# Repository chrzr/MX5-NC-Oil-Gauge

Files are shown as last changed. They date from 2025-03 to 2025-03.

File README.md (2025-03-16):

# MX5-NC-Oil-Gauge

So my inspiration was obviously the fantastic gauge kit from Rotarytronics! But as i did not want to modify my gauge cluster, I decided to try and come up with something myself :)
(the provided installation manual also gives some information about the installation process of the sensor)

I used the following hardware:

- Waveshare RP2040 1.28" LCD Touchscreen
  https://www.waveshare.com/rp2040-touch-lcd-1.28.htm
- Custom 3D printed gauge pod
  based on https://www.printables.com/model/538771-rp2040-lcd-128-msa
- Bosch 0261230340 combined oil pressure and temperature sensor
  https://www.speedingparts.de/p/motorsteuerung/motorsteuerung-4623/sensor/drucksensor/bosch-flssigkeitsdruck-und-temperatursensor-10bar-140-c.html you should be able to find the datasheet by searching for the partnumber
- Bosch F 02U B00 751-01 5 pin trapez connector for connecting the sensor
  https://www.bosch-motorsport-shop.com.au/mating-connector-5-pin-trapez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
- 1/4" NPT to M10x1.0 thread adaptor (oil filter housing is 1/4" NPT inner thread, sensor has M10x1.0 outer thread)
  https://www.speedingparts.de/p/kraftstoff-dash-leitungssysteme/an-anschlsse-an-leitungen/spd-an-fittings/mm-npt-npt-reduzierstck/14-npt-m10x10-verringerung.html (you should be able to find similar ones on aliexpress)
- ADS1115 ADC for data aquisition from the sensors
  https://www.az-delivery.de/en/products/analog-digitalwandler-ads1115-mit-i2c-interface
- 5V to 3.3 logic level converter to get the ADCs 5V I2C signal down to the 3.3V input level of the RP2040
  https://www.sparkfun.com/sparkfun-logic-level-converter-bi-directional.html
- 12V IN to 5V / 3.3V OUT Breadboard PSU
  https://www.az-delivery.de/en/products/mb102-breadboard
- Fuse tap (Mini fuse size) to get the 12V from the driverside footwell fusebox
  https://www.aliexpress.com/item/4000648828410.html
- Prototyping pcb for the ADC, LLC, and PSU
  https://www.aliexpress.com/item/1005008313272396.html
- A few meters of 4-strand 4x0,5 mm² sensor wire

The setup is as follows: The RP2040 with the LCD sits inside the gauge pod and is connected via an about 75cm long piece of an old USB cable to the ADC/PSU box, which I placed in the driver footwell area above the fusebox. The PSU gets 12V from the driver footwell fusebox and supplies 5V to the ADC and 3.3V to the RP2040. The sensor is directly connected to the ADC box (i routed the wire through the rubber grommet of the hood release cable)
The circuitry for interfacing the sensor was a bit fiddly ... be sure to connect the thermistor via a pull-down resistor (I used 1k Ohm)

Getting the old sensor out and installing the new one was a bit tricky because of the limited space + I have large hands and only had the car on jack stands. I would definitely recommend a long 27mm socket and some extensions.

Using snippets (mainly the driver part) from this repository: https://github.com/waveshareteam/RP2040-Touch-LCD-1.28

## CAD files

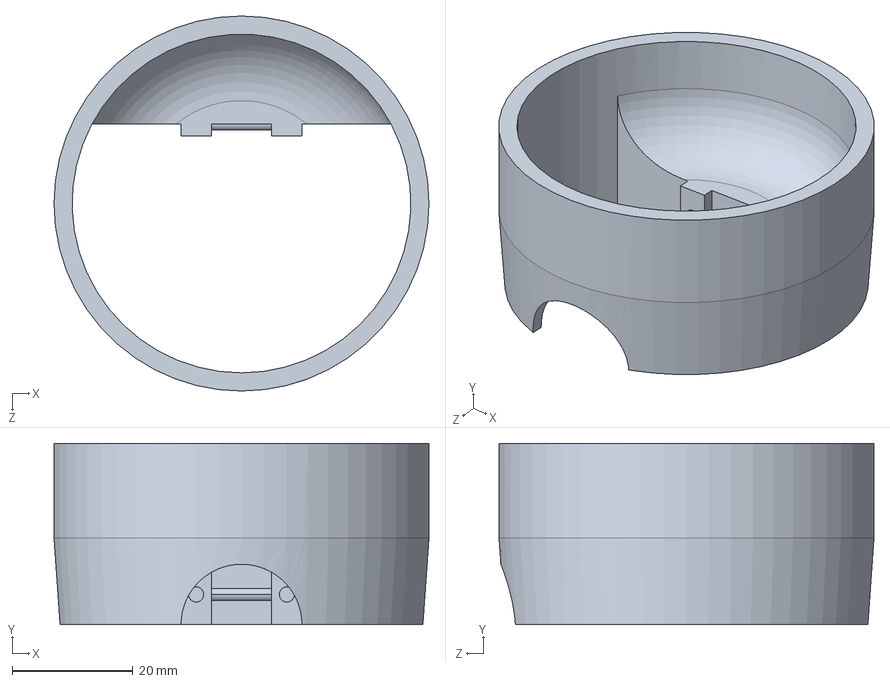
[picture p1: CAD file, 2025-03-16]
MX5_OilGaugePod.SLDPRT
62.0 x 30.0 x 62.0 mm

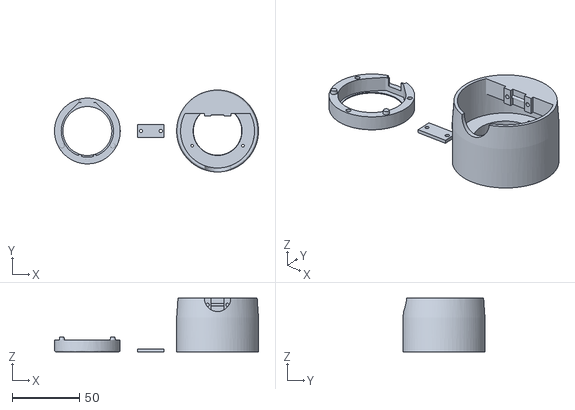
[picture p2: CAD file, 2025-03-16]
MX5_NC_GaugePod.stl
152.0 x 61.0 x 40.0

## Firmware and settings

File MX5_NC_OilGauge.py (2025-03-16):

from machine import Pin,I2C,SPI,PWM,Timer
import framebuf
import time
import math
Vbat_Pin = 29

#Pin definition  引脚定义
I2C_SDA = 6
I2C_SDL = 7

DC = 8
CS = 9
SCK = 10
MOSI = 11
MISO = 12
RST = 13

BL = 25

###########################################################################################################
####################################### DRIVERS START #####################################################
###########################################################################################################

#LCD Driver  LCD驱动
class LCD_1inch28(framebuf.FrameBuffer):
    def __init__(self): #SPI initialization  SPI初始化
        self.width = 240
        self.height = 240
        
        self.cs = Pin(CS,Pin.OUT)
        self.rst = Pin(RST,Pin.OUT)
        
        self.cs(1)
        self.spi = SPI(1,100_000_000,polarity=0, phase=0,bits= 8,sck=Pin(SCK),mosi=Pin(MOSI),miso=None)
        self.dc = Pin(DC,Pin.OUT)
        self.dc(1)
        self.buffer = bytearray(self.height * self.width * 2)
        super().__init__(self.buffer, self.width, self.height, framebuf.RGB565)
        self.init_display()
        
        #Define color, Micropython fixed to BRG format  定义颜色，Micropython固定为BRG格式
        self.red   =   0x07E0
        self.green =   0x001f
        self.blue  =   0xf800
        self.white =   0xffff
        self.black =   0x0000
        self.brown =   0X8430
        
        self.fill(self.white) #Clear screen  清屏
        self.show()#Show  显示

        self.pwm = PWM(Pin(BL))
        self.pwm.freq(5000) #Turn on the backlight  开背光
        
    def write_cmd(self, cmd): #Write command  写命令
        self.cs(1)
        self.dc(0)
        self.cs(0)
        self.spi.write(bytearray([cmd]))
        self.cs(1)

    def write_data(self, buf): #Write data  写数据
        self.cs(1)
        self.dc(1)
        self.cs(0)
        self.spi.write(bytearray([buf]))
        self.cs(1)
        
    def set_bl_pwm(self,duty): #Set screen brightness  设置屏幕亮度
        self.pwm.duty_u16(duty)#max 65535
        
    def init_display(self): #LCD initialization  LCD初始化
        """Initialize dispaly"""  
        self.rst(1)
        time.sleep(0.01)
        self.rst(0)
        time.sleep(0.01)
        self.rst(1)
        time.sleep(0.05)
        
        self.write_cmd(0xEF)
        self.write_cmd(0xEB)
        self.write_data(0x14) 
        
        self.write_cmd(0xFE) 
        self.write_cmd(0xEF) 

        self.write_cmd(0xEB)
        self.write_data(0x14) 

        self.write_cmd(0x84)
        self.write_data(0x40) 

        self.write_cmd(0x85)
        self.write_data(0xFF) 

        self.write_cmd(0x86)
        self.write_data(0xFF) 

        self.write_cmd(0x87)
        self.write_data(0xFF)

        self.write_cmd(0x88)
        self.write_data(0x0A)

        self.write_cmd(0x89)
        self.write_data(0x21) 

        self.write_cmd(0x8A)
        self.write_data(0x00) 

        self.write_cmd(0x8B)
        self.write_data(0x80) 

        self.write_cmd(0x8C)
        self.write_data(0x01) 

        self.write_cmd(0x8D)
        self.write_data(0x01) 

        self.write_cmd(0x8E)
        self.write_data(0xFF) 

        self.write_cmd(0x8F)
        self.write_data(0xFF) 


        self.write_cmd(0xB6)
        self.write_data(0x00)
        self.write_data(0x20)

        self.write_cmd(0x36)
        self.write_data(0x98)

        self.write_cmd(0x3A)
        self.write_data(0x05) 


        self.write_cmd(0x90)
        self.write_data(0x08)
        self.write_data(0x08)
        self.write_data(0x08)
        self.write_data(0x08) 

        self.write_cmd(0xBD)
        self.write_data(0x06)
        
        self.write_cmd(0xBC)
        self.write_data(0x00)

        self.write_cmd(0xFF)
        self.write_data(0x60)
        self.write_data(0x01)
        self.write_data(0x04)

        self.write_cmd(0xC3)
        self.write_data(0x13)
        self.write_cmd(0xC4)
        self.write_data(0x13)

        self.write_cmd(0xC9)
        self.write_data(0x22)

        self.write_cmd(0xBE)
        self.write_data(0x11) 

        self.write_cmd(0xE1)
        self.write_data(0x10)
        self.write_data(0x0E)

        self.write_cmd(0xDF)
        self.write_data(0x21)
        self.write_data(0x0c)
        self.write_data(0x02)

        self.write_cmd(0xF0)   
        self.write_data(0x45)
        self.write_data(0x09)
        self.write_data(0x08)
        self.write_data(0x08)
        self.write_data(0x26)
        self.write_data(0x2A)

        self.write_cmd(0xF1)    
        self.write_data(0x43)
        self.write_data(0x70)
        self.write_data(0x72)
        self.write_data(0x36)
        self.write_data(0x37)  
        self.write_data(0x6F)


        self.write_cmd(0xF2)   
        self.write_data(0x45)
        self.write_data(0x09)
        self.write_data(0x08)
        self.write_data(0x08)
        self.write_data(0x26)
        self.write_data(0x2A)

        self.write_cmd(0xF3)   
        self.write_data(0x43)
        self.write_data(0x70)
        self.write_data(0x72)
        self.write_data(0x36)
        self.write_data(0x37) 
        self.write_data(0x6F)

        self.write_cmd(0xED)
        self.write_data(0x1B) 
        self.write_data(0x0B) 

        self.write_cmd(0xAE)
        self.write_data(0x77)
        
        self.write_cmd(0xCD)
        self.write_data(0x63)


        self.write_cmd(0x70)
        self.write_data(0x07)
        self.write_data(0x07)
        self.write_data(0x04)
        self.write_data(0x0E) 
        self.write_data(0x0F) 
        self.write_data(0x09)
        self.write_data(0x07)
        self.write_data(0x08)
        self.write_data(0x03)

        self.write_cmd(0xE8)
        self.write_data(0x34)

        self.write_cmd(0x62)
        self.write_data(0x18)
        self.write_data(0x0D)
        self.write_data(0x71)
        self.write_data(0xED)
        self.write_data(0x70) 
        self.write_data(0x70)
        self.write_data(0x18)
        self.write_data(0x0F)
        self.write_data(0x71)
        self.write_data(0xEF)
        self.write_data(0x70) 
        self.write_data(0x70)

        self.write_cmd(0x63)
        self.write_data(0x18)
        self.write_data(0x11)
        self.write_data(0x71)
        self.write_data(0xF1)
        self.write_data(0x70) 
        self.write_data(0x70)
        self.write_data(0x18)
        self.write_data(0x13)
        self.write_data(0x71)
        self.write_data(0xF3)
        self.write_data(0x70) 
        self.write_data(0x70)

        self.write_cmd(0x64)
        self.write_data(0x28)
        self.write_data(0x29)
        self.write_data(0xF1)
        self.write_data(0x01)
        self.write_data(0xF1)
        self.write_data(0x00)
        self.write_data(0x07)
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

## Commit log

2025-03-16 initial commit
    Added python script and STL file for NC air vent gauge pod
    [MX5_NC_GaugePod.stl]
2025-03-16 added Solidworks base file for NC vent adaptor
    [MX5_OilGaugePod.SLDPRT]

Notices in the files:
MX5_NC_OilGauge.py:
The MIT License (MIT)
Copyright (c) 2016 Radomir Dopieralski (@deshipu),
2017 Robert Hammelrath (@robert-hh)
